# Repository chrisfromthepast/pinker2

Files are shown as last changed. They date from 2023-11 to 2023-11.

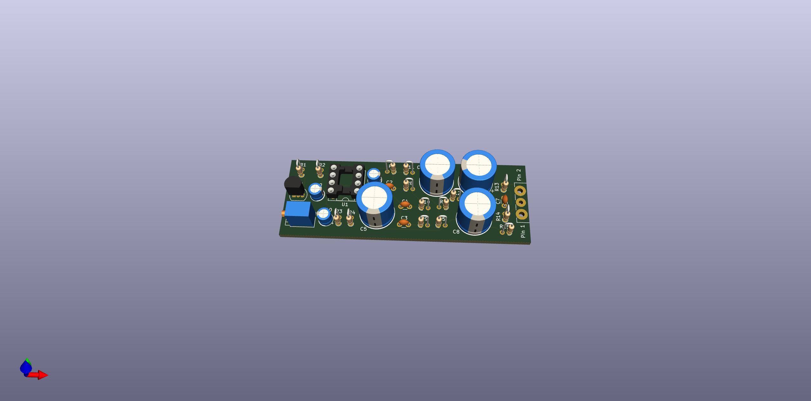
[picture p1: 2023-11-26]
3d view.jpg

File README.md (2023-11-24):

# pinker2
 Phantom Powered Pink noise generator

Plug it into a +48V Phantom Powered mic preamp to create pink noise.

Thia project is still in development, and owes EVERYTHING to this thread:
https://groupdiy.com/threads/will-this-48-v-pink-noise-source-work.85625/page-4#post-1117816

A reverse biased BJT provides noise, a op amp gain stage comes next, followed by an op amp filter stage, which does its best to turn white noise into pink noise. the output is impedance balanced.

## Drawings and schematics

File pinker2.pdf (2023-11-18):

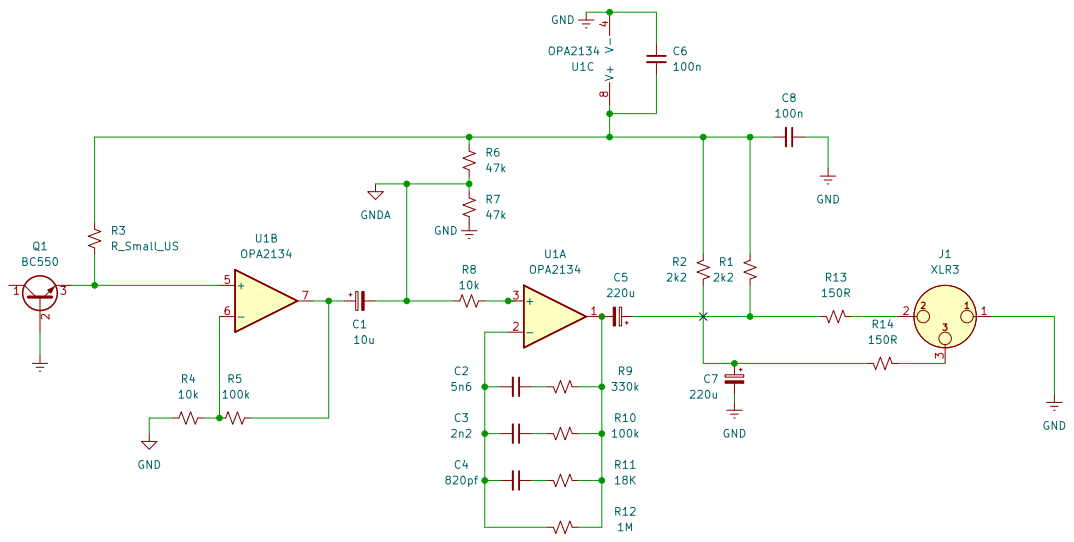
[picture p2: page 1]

File: pinker2.kicad_sch Sheet: / Chris Wiliiams R10

Id: 1/1 Title: 48V pink noise source

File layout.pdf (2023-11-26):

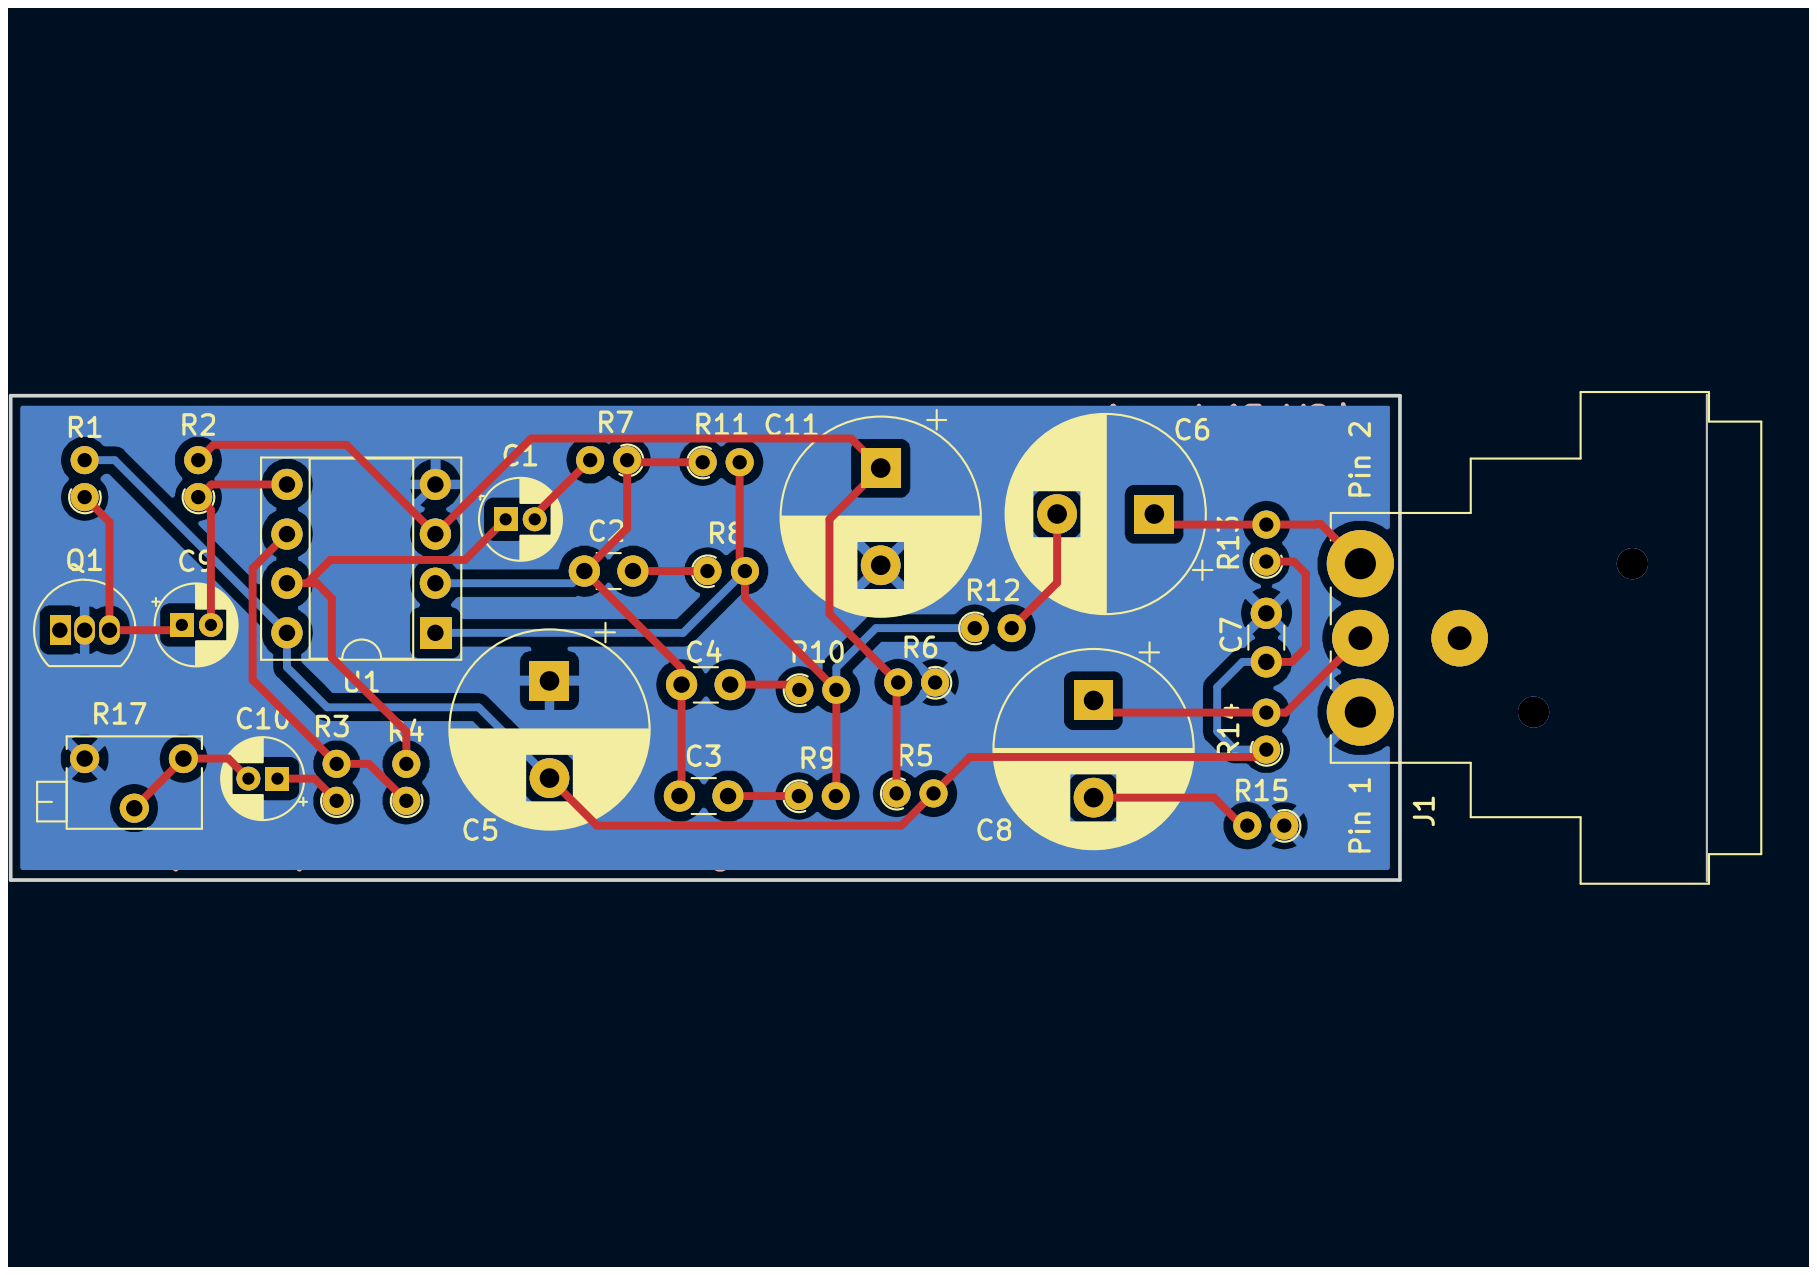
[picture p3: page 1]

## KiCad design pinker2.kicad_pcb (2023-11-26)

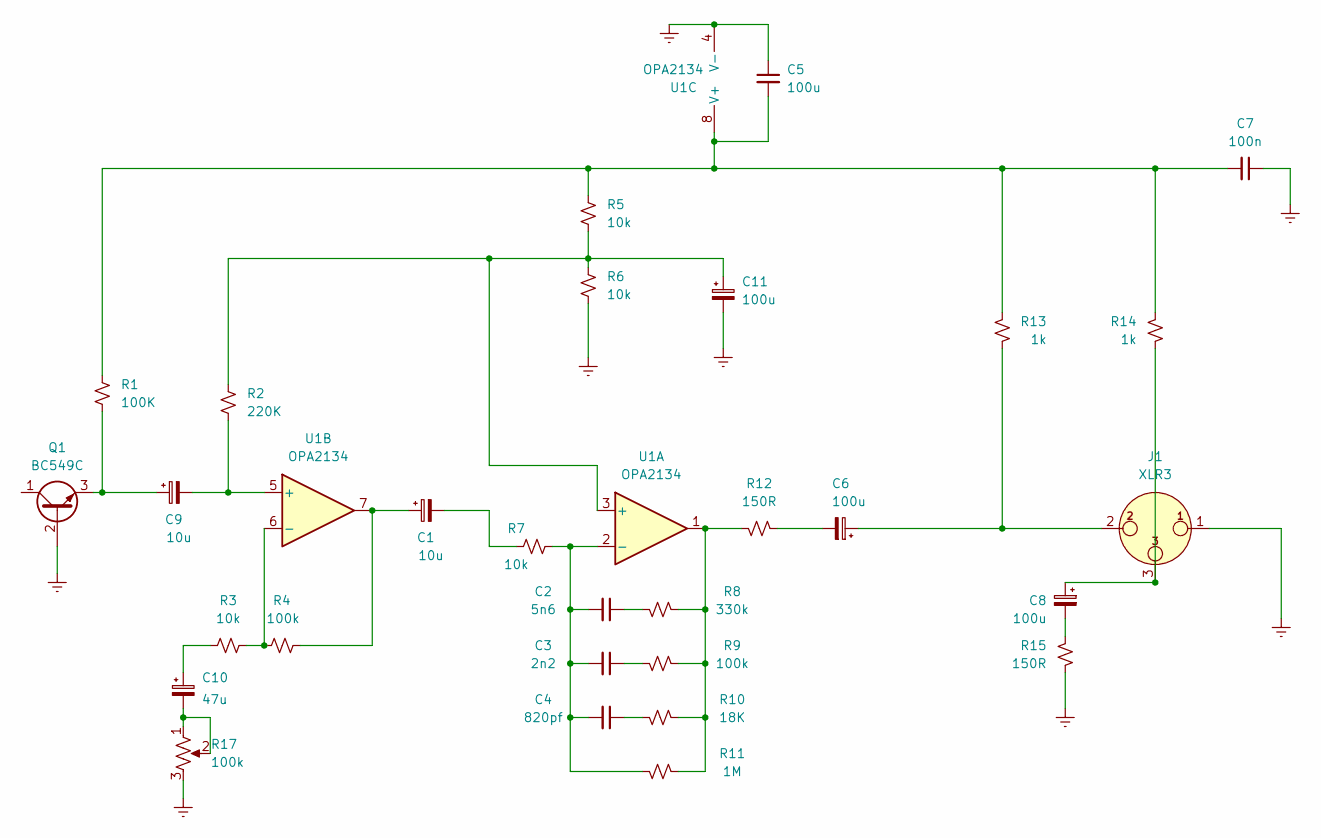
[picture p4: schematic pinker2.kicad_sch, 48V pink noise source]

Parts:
C1, C9: 10u; CP_Radial_D4.0mm_P1.50mm
C2: 5n6; C_Disc_D3.0mm_W1.6mm_P2.50mm
C3: 2n2; C_Disc_D3.0mm_W1.6mm_P2.50mm
C4: 820pf; C_Disc_D3.0mm_W1.6mm_P2.50mm
C5, C6, C8, C11: 100u; CP_Radial_D10.0mm_P5.00mm
C7: 100n; C_Disc_D3.0mm_W1.6mm_P2.50mm
C10: 47u; CP_Radial_D4.0mm_P1.50mm
J1: XLR3; Jack_XLR_Neutrik_NC3MBH_Horizontal
Q1: BC549C; TO-92_Inline
R1: 100K; R_Axial_DIN0204_L3.6mm_D1.6mm_P1.90mm_Vertical
R2: 220K; R_Axial_DIN0204_L3.6mm_D1.6mm_P1.90mm_Vertical
R3, R5, R6, R7: 10k; R_Axial_DIN0204_L3.6mm_D1.6mm_P1.90mm_Vertical
R4, R9: 100k; R_Axial_DIN0204_L3.6mm_D1.6mm_P1.90mm_Vertical
R8: 330k; R_Axial_DIN0204_L3.6mm_D1.6mm_P1.90mm_Vertical
R10: 18K; R_Axial_DIN0204_L3.6mm_D1.6mm_P1.90mm_Vertical
R11: 1M; R_Axial_DIN0204_L3.6mm_D1.6mm_P1.90mm_Vertical
R12, R15: 150R; R_Axial_DIN0204_L3.6mm_D1.6mm_P1.90mm_Vertical
R13, R14: 1k; R_Axial_DIN0204_L3.6mm_D1.6mm_P1.90mm_Vertical
R17: 100k; Potentiometer_Bourns_3266X_Horizontal
U1: OPA2134; DIP-8_W7.62mm_Socket

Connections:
Earth: C5.1, C7.1, C11.2, J1.1, Q1.2 (B), R6.1, R15.1, R17.3, U1.4 (V-)
unnamed: C1.1, R4.2, U1.7
unnamed: C1.2, R7.2
unnamed: C2.1, R8.1
unnamed: C2.2, C3.2, C4.2, R7.1, R11.1, U1.2 (-)
unnamed: C3.1, R9.1
unnamed: C4.1, R10.1
unnamed: C5.2, C7.2, R1.2, R5.2, R13.1, R14.1, U1.8 (V+)
unnamed: C6.1, J1.2, R13.2
unnamed: C6.2, R12.2
unnamed: C8.1, J1.3, R14.2
unnamed: C8.2, R15.2
unnamed: C9.1, Q1.3 (E), R1.1
unnamed: C9.2, R2.1, U1.5 (+)
unnamed: C10.1, R3.1
unnamed: C10.2, R17.1, R17.2
unnamed: C11.1, R2.2, R5.1, R6.2, U1.3 (+)
unnamed: R3.2, R4.1, U1.6 (-)
unnamed: R8.2, R9.2, R10.2, R11.2, R12.1, U1.1

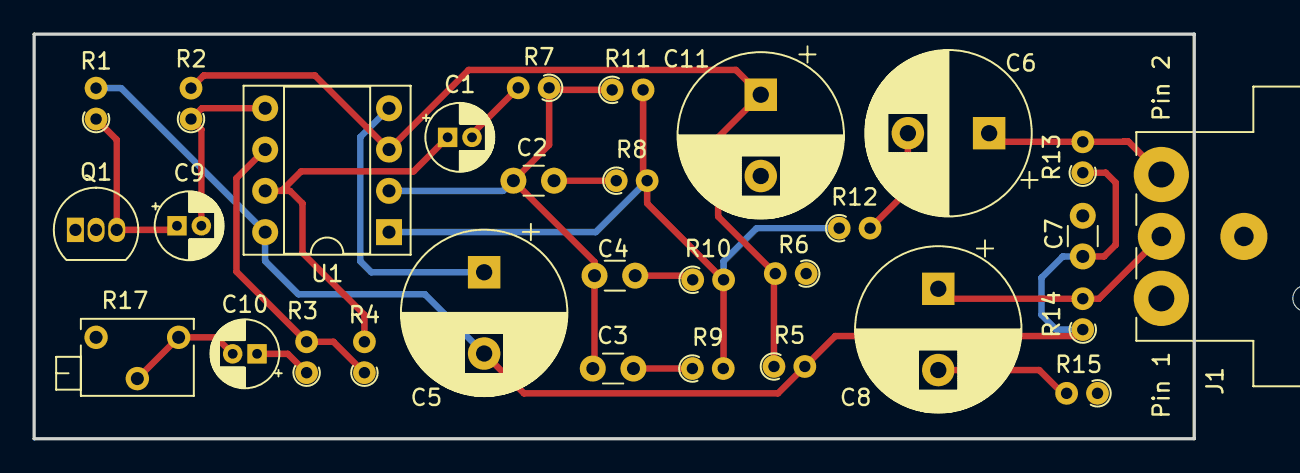
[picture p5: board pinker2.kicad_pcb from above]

Board: 2 copper layers, 71.4 x 24.9 mm, 30 parts (0 on the bottom side), 19 nets.

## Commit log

2023-11-18 Made Repository
    After the schematic is pretty much final
2023-11-25 layout progress
    started adding traces
    [pinker2.kicad_pcb, pinker2.kicad_sch]
2023-11-25 revised to all THT
    changed the pot and the Op amp footprints to through hole
    [pinker2-B_Cu.gbr, pinker2-B_Mask.gbr, pinker2-B_Paste.gbr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]
2023-11-26 almost complete
    nudged some items, added a ground pour, linked the footprints to a local library (hopefully symbols live there too) added a pdf of the layout to help with visual diffs
    [pinker2-B_Cu.gbr, pinker2-B_Mask.gbr, pinker2-B_Paste.gbr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]
2023-11-26 mostly complete
    added some silkscreen notes, and deleted some junk files
    [pinker2-B_Cu.gbr, pinker2-B_Mask.gbr, pinker2-B_Paste.gbr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]
